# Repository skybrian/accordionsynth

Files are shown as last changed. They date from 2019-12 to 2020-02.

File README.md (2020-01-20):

# An accordion synthesizer project

My goal is to eventually replicate the keyboard and sound of the bass side of an accordion in an electronic device that accordion players will find easy to adapt to. So far I've built three prototypes:

  * Prototype 1 was trying out a Teensy 4 with an audio shield on a breadboard, with 4 bass buttons.
  * For prototype 2, I put the buttons on two double-decker circuit boards (9 bass buttons).
   Here's the [Video](https://www.youtube.com/watch?v=f6V9Kw87OYE). You can see the remains of prototype 1 in the background.
  * For prototype 3, I built a real case out of wood and laser-cut acrylic panels, to make a desktop device that's more easily portable. This one uses a Teensy 3.6. Here's the [Video](https://www.youtube.com/watch?v=nj9DO6gRxgs). I designed it in Onshape and you can [look at the CAD model online](https://cad.onshape.com/documents/49e3bde7fd0cf848110a849c/w/f0f076d4e6eda68337d8a8fa/e/61a0bfc531c55ddd0f7d8f48).

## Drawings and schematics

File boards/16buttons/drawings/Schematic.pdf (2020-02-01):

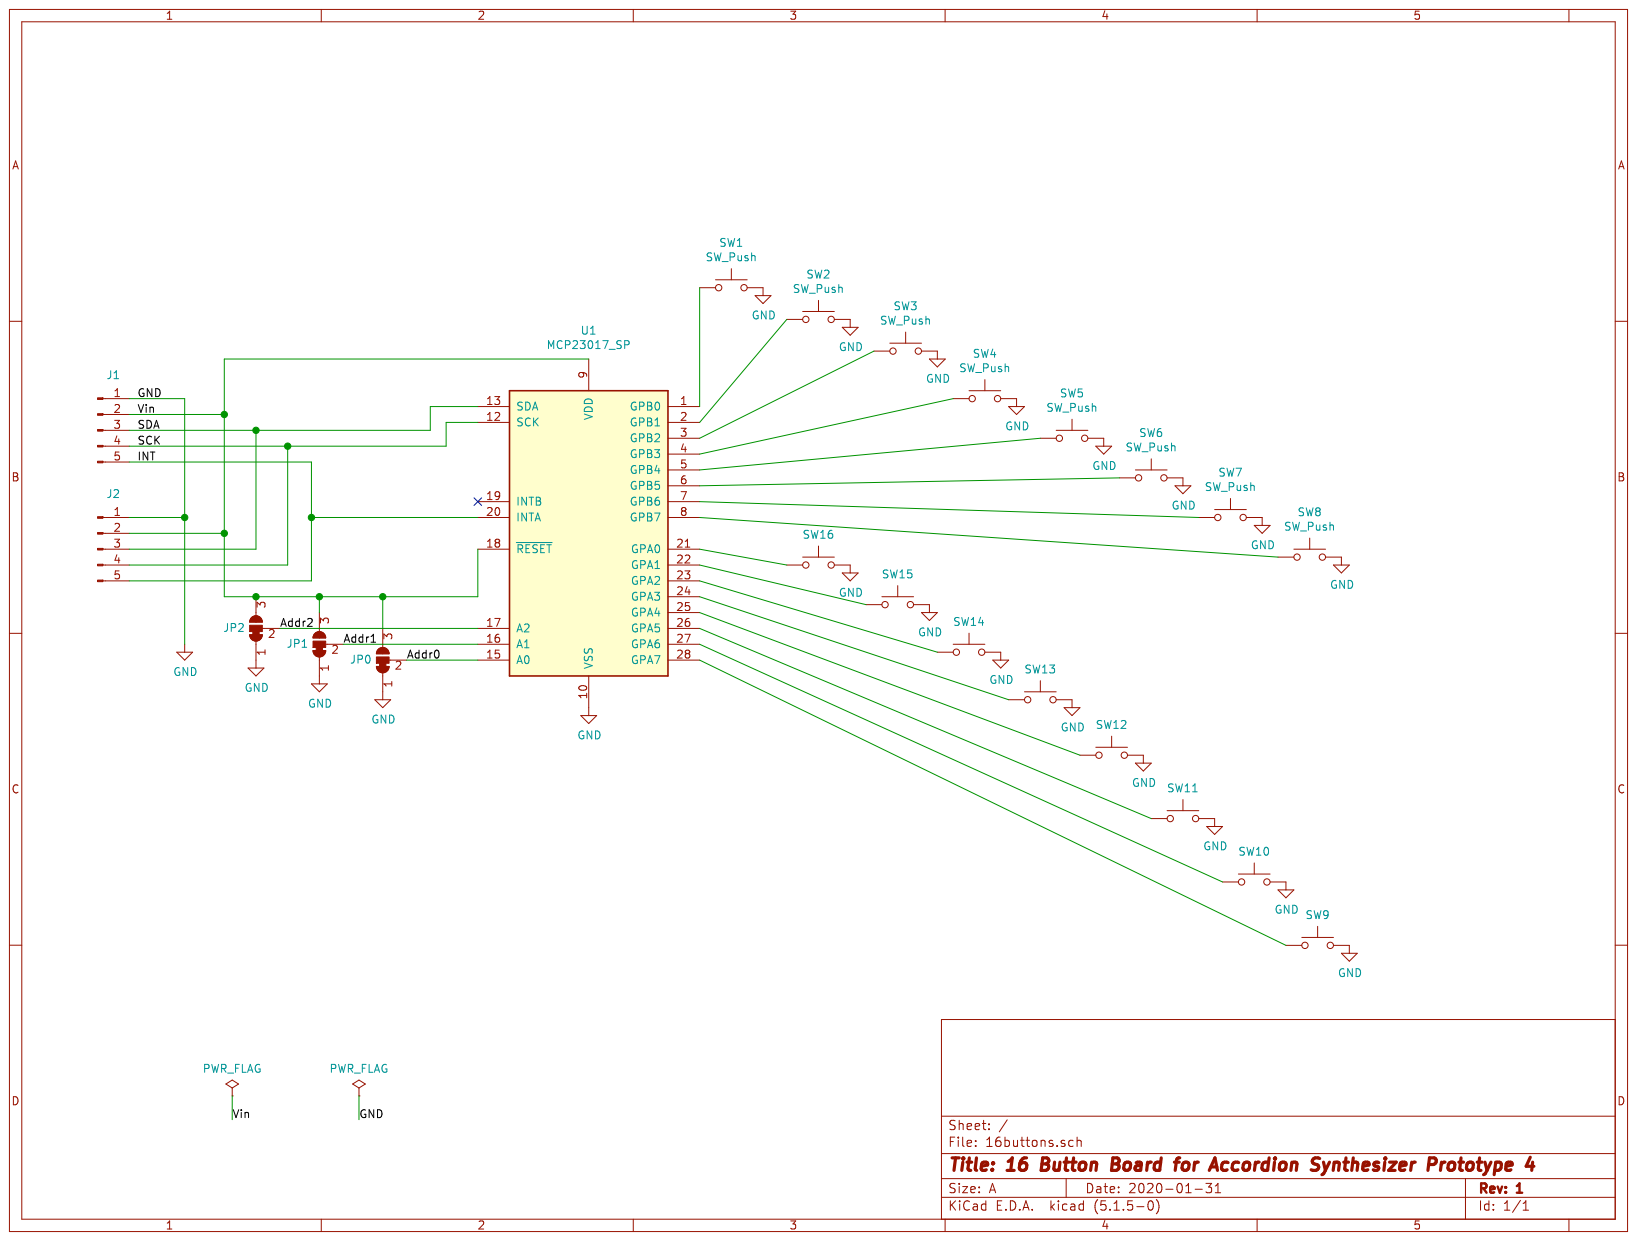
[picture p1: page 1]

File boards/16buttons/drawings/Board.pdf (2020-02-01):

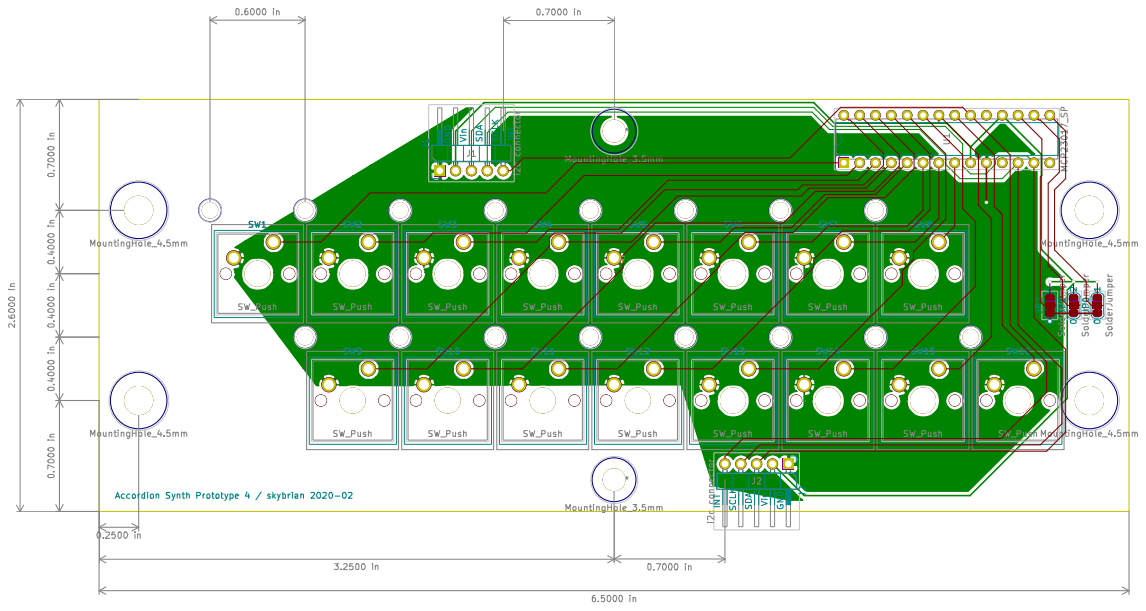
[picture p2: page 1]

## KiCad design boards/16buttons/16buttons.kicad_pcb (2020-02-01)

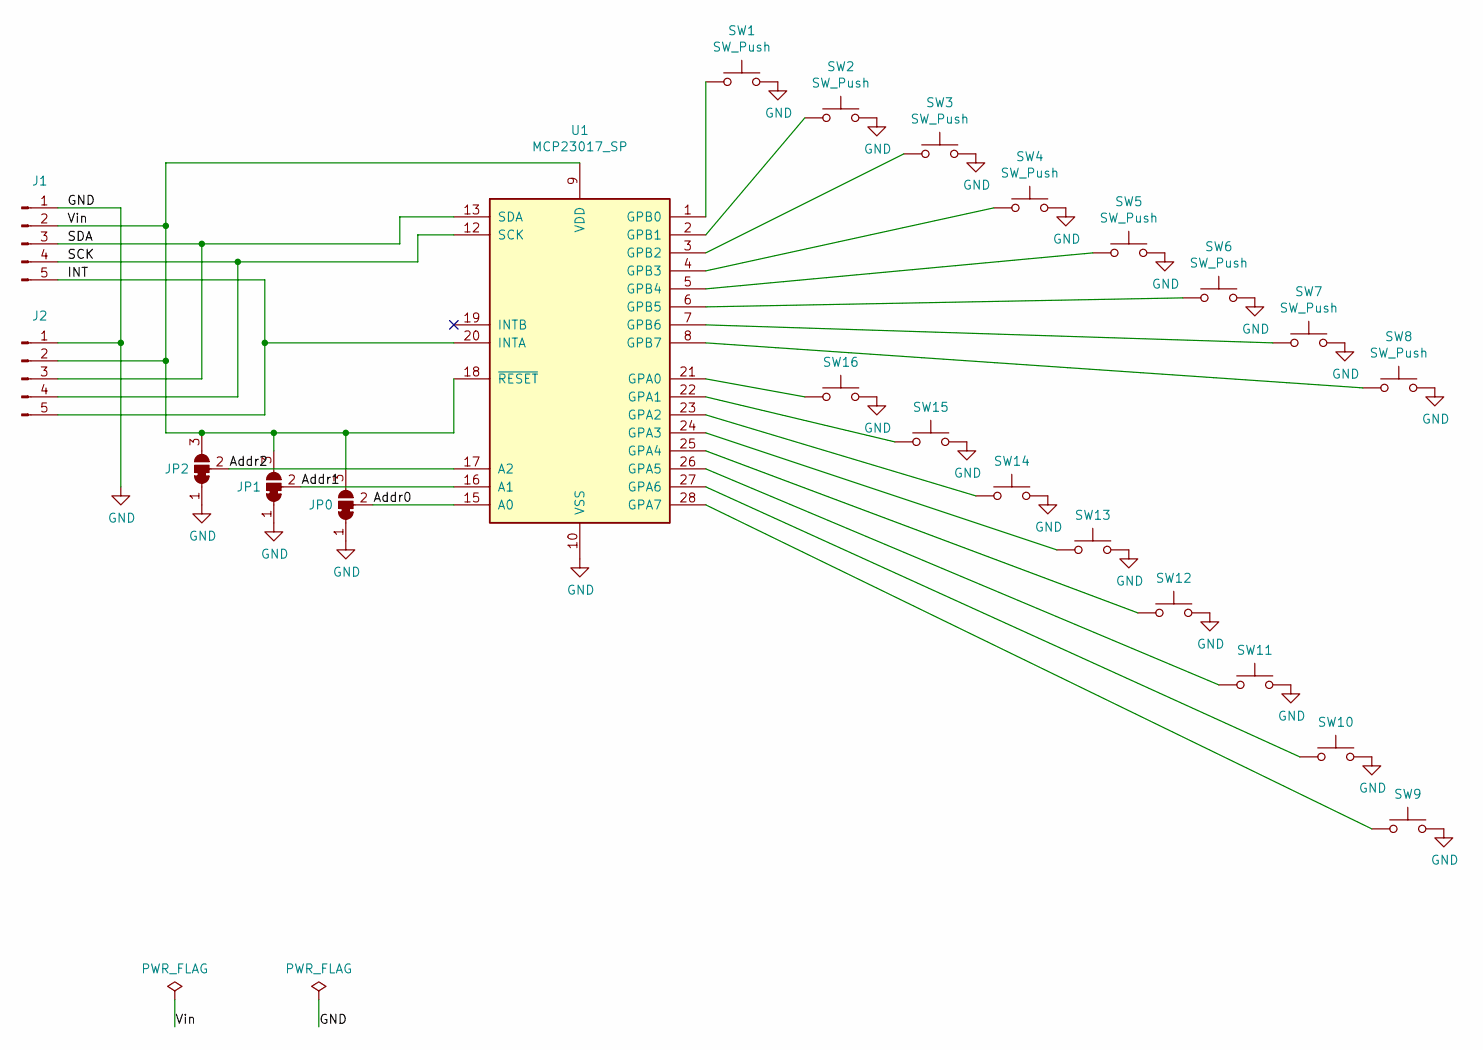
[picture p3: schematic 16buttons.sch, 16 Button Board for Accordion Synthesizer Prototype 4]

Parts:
J1, J2: i2c connector; PinHeader_i2c
JP0, JP1, JP2: SolderJumper; SolderJumper_Bridged12
SW1, SW2, SW3, SW4, SW5, SW6, SW7, SW8, SW9, SW10, SW11, SW12, SW13, SW14, SW15, SW16: SW_Push; SW_Gateron_Trim
U1: MCP23017_SP; DIP-28_W7.62mm

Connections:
/Addr0: JP0.2 (C), U1.15 (A0)
/Addr1: JP1.2 (C), U1.16 (A1)
/Addr2: JP2.2 (C), U1.17 (A2)
/INT: J1.5, J2.5, U1.20 (INTA)
/SCK: J1.4, J2.4, U1.12 (SCK)
/SDA: J1.3, J2.3, U1.13 (SDA)
/Vin: J1.2, J2.2, JP0.3 (B), JP1.3 (B), JP2.3 (B), U1.9 (VDD), U1.18 (~RESET~)
GND: J1.1, J2.1, JP0.1 (A), JP1.1 (A), JP2.1 (A), SW1.2, SW2.2, SW3.2, SW4.2, SW5.2, SW6.2, SW7.2, SW8.2, SW9.2, SW10.2, SW11.2, SW12.2, SW13.2, SW14.2, SW15.2, SW16.2, U1.10 (VSS)
unnamed: SW1.1, U1.1 (GPB0)
unnamed: SW2.1, U1.2 (GPB1)
unnamed: SW3.1, U1.3 (GPB2)
unnamed: SW4.1, U1.4 (GPB3)
unnamed: SW5.1, U1.5 (GPB4)
unnamed: SW6.1, U1.6 (GPB5)
unnamed: SW7.1, U1.7 (GPB6)
unnamed: SW8.1, U1.8 (GPB7)
unnamed: SW9.1, U1.28 (GPA7)
unnamed: SW10.1, U1.27 (GPA6)
unnamed: SW11.1, U1.26 (GPA5)
unnamed: SW12.1, U1.25 (GPA4)
unnamed: SW13.1, U1.24 (GPA3)
unnamed: SW14.1, U1.23 (GPA2)
unnamed: SW15.1, U1.22 (GPA1)
unnamed: SW16.1, U1.21 (GPA0)

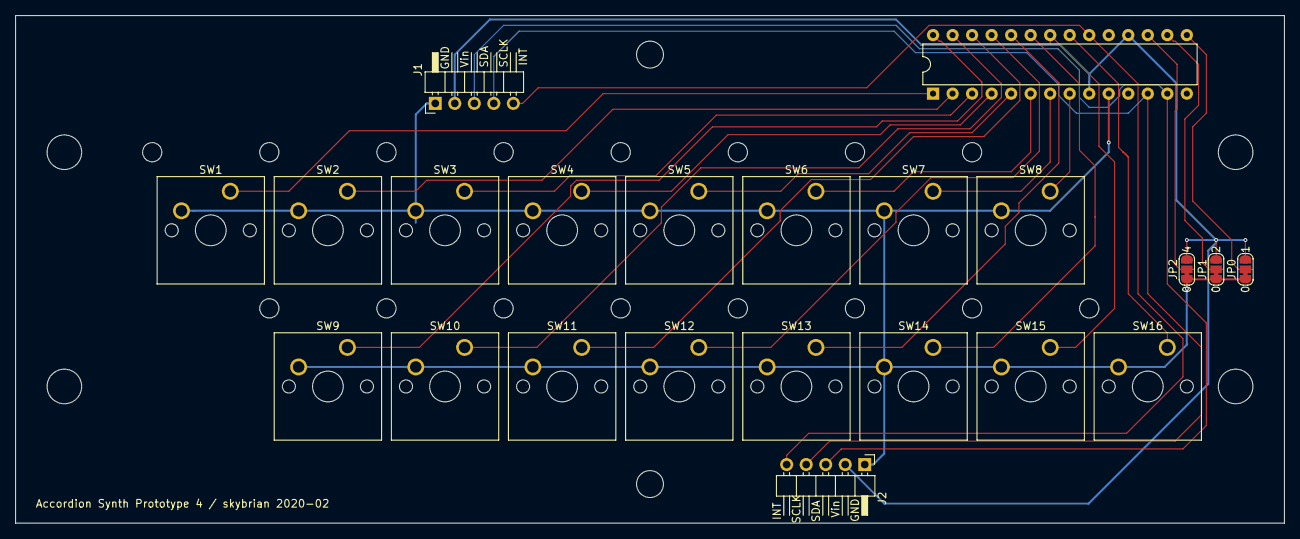
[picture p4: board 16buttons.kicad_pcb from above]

Board: 2 copper layers, 165.1 x 66.0 mm, 22 parts (0 on the bottom side), 24 nets.

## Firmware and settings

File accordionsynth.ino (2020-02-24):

#include <Audio.h>
#include <Metro.h>
#include <Wire.h>
#include <SPI.h>
#include <SD.h>


#include "midi.h"
using namespace midi;

#include "sound.h"
using namespace sound;

#include "key.h"
#include "bellows.h"

const Chord startSong[] = {
  Chord(F3),
  Chord(midi::A3),
  Chord(C4),
  Chord::majorUp(F3)
};

// Uses notes from E3 to D#4
key::Layout highStradella = {{
  {Chord(midi::A3), Chord(E3), Chord(B3), Chord(F3+1)}, // counterbass row
  {Chord(F3), Chord(C4), Chord(G3), Chord(D4)}, // bass row
  {Chord::majorUp(F3), Chord::majorDown(C4), Chord::majorUp(G3), Chord::majorDown(D4)}, // major chord row
  {Chord::minorUp(F3), Chord::minorMid(C4), Chord::minorUp(G3), Chord::minorDown(D4)} // minor chord row
}};

// Uses bass notes from G1-F#2, chords E3 to D#4
key::Layout lowStradella = {{
  {Chord(midi::A1), Chord(E2), Chord(C2-1), Chord(F2+1)}, // counterbass row
  {Chord(F2), Chord(C2), Chord(G1), Chord(D2)}, // bass row
  {Chord::majorUp(F3), Chord::majorDown(C4), Chord::majorUp(G3), Chord::majorDown(D4)}, // major chord row
  {Chord::minorUp(F3), Chord::minorMid(C4), Chord::minorUp(G3), Chord::minorDown(D4)} // minor chord row
}};

AudioControlSGTL5000 shield;
Bank bank(G1);
AudioFilterBiquad filter;
AudioSynthWaveformDc dc;
AudioEffectMultiply gain;

AudioOutputI2S out;
MidiChannel midiChannel(1);

AudioConnection patches[] = {
  AudioConnection(bank.out(), 0, filter, 0),
  AudioConnection(filter, 0, gain, 0),
  AudioConnection(dc, 0, gain, 1),
  AudioConnection(gain, 0, out, 0),
  AudioConnection(gain, 0, out, 1)
};

#define LENGTH(x) (sizeof(x)/sizeof(x[0]))

// Don't use pins already in use by audio shield.
// We have two boards with different column-enabling pins.
const key::ColumnPins botColPins = {36, 35, 34, 33};
const key::ColumnPins midColPins = {29, 30, 31, 32};

// Read all the same rows for both, but half the rows won't work for each board.
const key::RowPins rowPins = {27, 37, 28, 38};

key::Board bottomBoard = key::Board(botColPins, rowPins);
key::Board middleBoard = key::Board(midColPins, rowPins);

const int led = 13;

const int audioMemory = 20;

const double sortaNotch[] = {1.0, 1.93, 0.948, 1.85, 0.863}; 

void setup() {
  Serial.begin(9600);
  AudioMemory(audioMemory);
  filter.setLowpass(0, 3863, 0.707);
  filter.setLowpass(1, 3863, 0.707);
  filter.setCoefficients(3, sortaNotch);
  dc.amplitude(0.3);
  shield.enable();
  shield.volume(0.9);
  dc.amplitude(1.0);
  bottomBoard.setupPins();
  middleBoard.setupPins();
  pinMode(led, OUTPUT);

  bellows::begin();

  playStartSong(bank);
  Serial.println("Ready.\n");
//  Serial.print("Audio memory used: ");
//  Serial.print(AudioMemoryUsageMax());
//  Serial.print(" blocks.\nProcessor usage: ");
//  Serial.print(AudioProcessorUsageMax());
//  Serial.println("%");

  bellows::update();
}

void playStartSong(Bank& bank) {
  for (unsigned i = 0; i < LENGTH(startSong); i++) {
    Chord ch = startSong[i];
//    ch.printTo(Serial);
//    Serial.println();

    digitalWrite(led, HIGH);
    bank.notesOn(ch);
    delay(300);
    bank.notesOff();
    digitalWrite(led, LOW);
    delay(100);
  }  
}

Metro cpuInterval(10*1000);

void checkProcessorUsage() {
  if (cpuInterval.check()) {
    int usage = AudioProcessorUsageMax();
    if (usage > 90) {
      Serial.print("Processor usage: ");
      Serial.print(usage);
      Serial.print("% Max memory: ");
      Serial.print(AudioMemoryUsageMax());
      Serial.print(" of ");
      Serial.println(audioMemory);
      AudioProcessorUsageMaxReset();
    }
    cpuInterval.reset();
  }
}

key::Layout layout = lowStradella;

Metro plotInterval(10);

void loop() {
  Chord next = bottomBoard.poll(layout) + middleBoard.poll(layout);
  bank.notesOn(next);
  midiChannel.send(next);

  if (bellows::update()) {
    float amp = bellows::pressure();
    dc.amplitude(amp, 5);
    bellows::plot(Serial);
  }

  while (usbMIDI.read()) {} // discard incoming

  checkProcessorUsage();
//  if (plotInterval.check()) {
//    bank.plotReedState(Serial, E4-1);
//  }
  delay(1);
}

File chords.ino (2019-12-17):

#include <Audio.h>
#include <Wire.h>
#include <SPI.h>
#include <SD.h>

#include "midi.h"
using namespace midi;

#include "sound.h"
using namespace sound;

#include "key.h"

const Chord startSong[] = {
  Chord::octave(F2),
  Chord::octave(midi::A2),
  Chord::octave(C2),
  Chord::major(F2)
};

key::Layout middleLayout = {
  {Chord::octave(midi::A2), Chord::octave(E2), Chord::octave(B2), Chord::octave(F2+1)}, // counterbass row
  {Chord::major(F2), Chord::major(C2), Chord::major(G2), Chord::major(D2)} // major chord row
};

key::Layout bottomLayout = {
  {Chord::octave(midi::F2), Chord::octave(C2), Chord::octave(G2), Chord::octave(D2)}, // bass row
  {Chord::minor(F2), Chord::minor(C2), Chord::minor(G2), Chord::minor(D2)} // minor chord row
};

AudioControlSGTL5000 shield;
Bank lowBank(G2);
Bank highBank(E3);
AudioMixer4 mixer;
AudioOutputI2S out;

AudioConnection patches[] = {
  AudioConnection(lowBank.out(), 0, mixer, 0),
  AudioConnection(highBank.out(), 0, mixer, 1),
  AudioConnection(mixer, 0, out, 0),
  AudioConnection(mixer, 0, out, 1),
};

#define LENGTH(x) (sizeof(x)/sizeof(x[0]))

// Don't use pins already in use by audio shield.
const key::ColumnPins botColPins = {36, 35, 34, 33};
const key::RowPins botRowPins = {37, 38};

const key::ColumnPins midColPins = {29, 30, 31, 32};
const key::RowPins midRowPins = {27, 28};

key::Board bottomBoard = key::Board(botColPins, botRowPins);
key::Board middleBoard = key::Board(midColPins, midRowPins);

void setup() {
  Serial.begin(9600);
  AudioMemory(20);
  shield.enable();
  shield.volume(0.25);
  bottomBoard.setupPins();
  middleBoard.setupPins();

  playStartSong(highBank);
  Serial.print("Ready.\nAudio memory used: ");
  Serial.print(AudioMemoryUsageMax());
  Serial.print(" blocks.\nProcessor usage: ");
  Serial.print(AudioProcessorUsageMax());
  Serial.println("%");
}

void playStartSong(Bank& bank) {
  for (unsigned i = 0; i < LENGTH(startSong); i++) {
    Chord ch = startSong[i];
//    ch.printTo(Serial);
//    Serial.println();
    bank.notesOn(ch);
    delay(300);
    bank.notesOff();
    delay(100);
  }  
}

void loop() {
  Chord next = bottomBoard.poll(bottomLayout) + middleBoard.poll(middleLayout);
  highBank.notesOn(next);
  delay(1);  
}

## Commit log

2019-11-07 4 bass buttons
2019-11-24 add startup song, fix ghost keys
    [chords.ino, key.h]
2019-12-19 turn up volume, blink LED on startup
2019-12-31 use a different hack to handle multiple boards
2020-01-13 switch to sawtooth and filter; E flat wasn't playing in C minor chord
2020-01-14 make detuned sawtooths actually work and fix bug where notes stopped working
    [accordionsynth.ino, sound.h]
2020-01-14 fix oscillator hard-sync, adjust envelope and Shepard tones
    [sound.h]
2020-01-20 add README pointing to video and CAD design
2020-01-31 add KiCAD project for proto 4 board
    [16buttons.kicad_pcb, 16buttons.sch]
2020-02-01 board tweaks before OSH Park order
    [16buttons.kicad_pcb, 16buttons.sch]
2020-02-01 add drawings for 16 button board
    [16buttons.sch]
2020-02-06 improve sound when holding a button down
2020-02-15 now using hinge and accelerometer for bellows
2020-02-24 switch to using a gyro sensor for angular velocity
2020-02-24 tweaked pressure curve
2020-02-25 switch to table for pressure curve
